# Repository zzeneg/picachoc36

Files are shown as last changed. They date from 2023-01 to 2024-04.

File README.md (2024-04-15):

# PicaChoc36

Low-profile split keyboard with 36 keys using XIAO controllers.

_Pica pica - european (common) magpie_

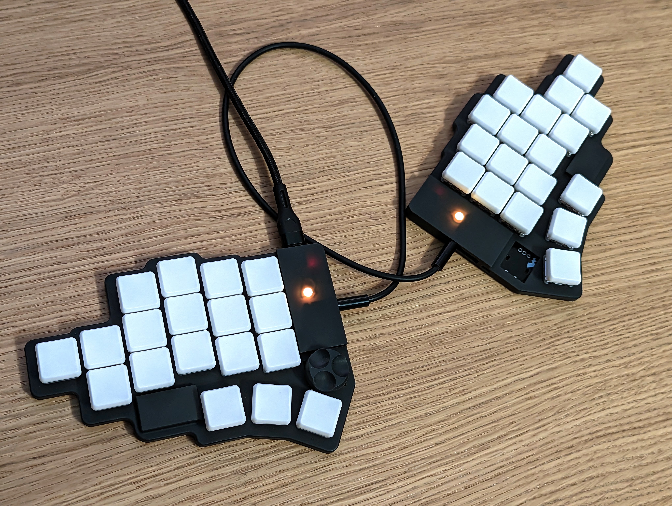
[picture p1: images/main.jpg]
main


## Features

- reversible PCB
- 36 soldered ChocV1 keys
- wired/wireless versions
- top pinky key moved to side
- 3D printed case

### Wired version

- XIAO RP 2040 controller
- QMK firmware
- TRRS or USB-C connection between halves
- rotary encoder on one side
- one status LED

### Wireless version

- XIAO BLE controller
- _[TODO]_ ZMK firmware
- rotary encoder on both sides (ZMK supports only main side for now)
- on/off toggle
- battery connectors

## Photos

wired version with 3d printed case

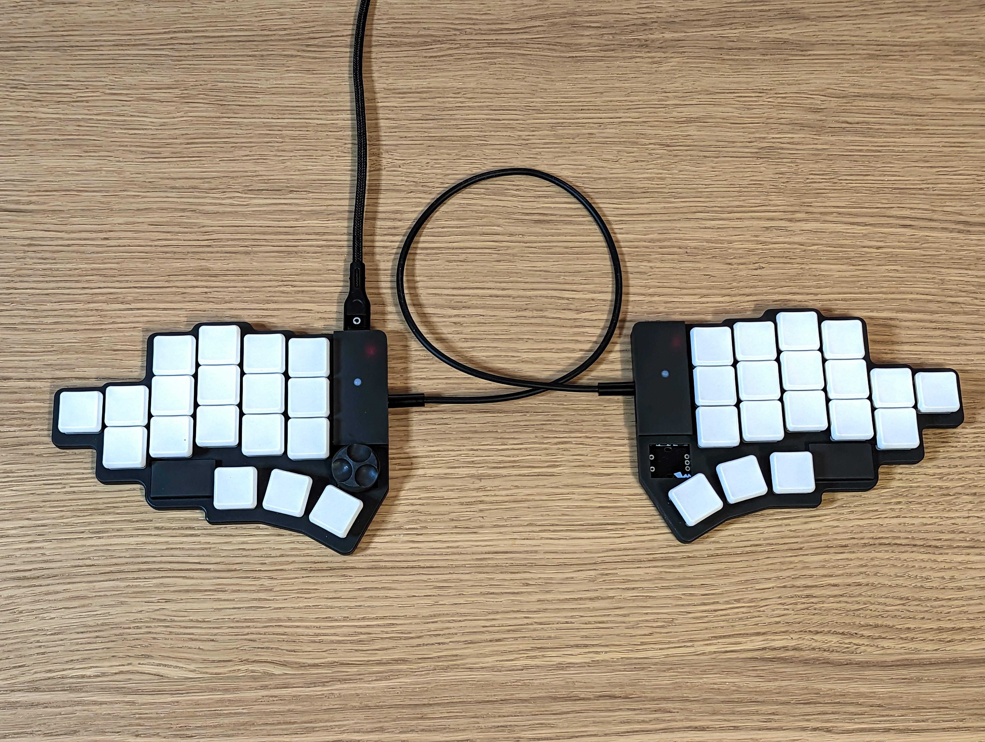
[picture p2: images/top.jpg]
top

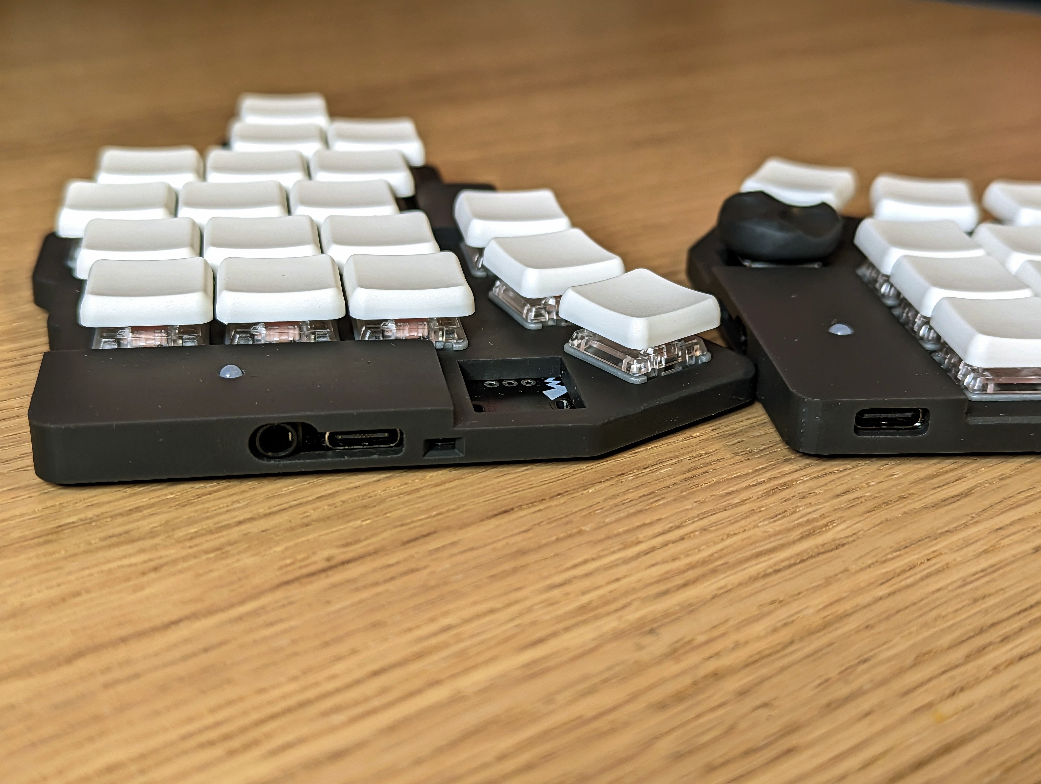
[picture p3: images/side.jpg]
side

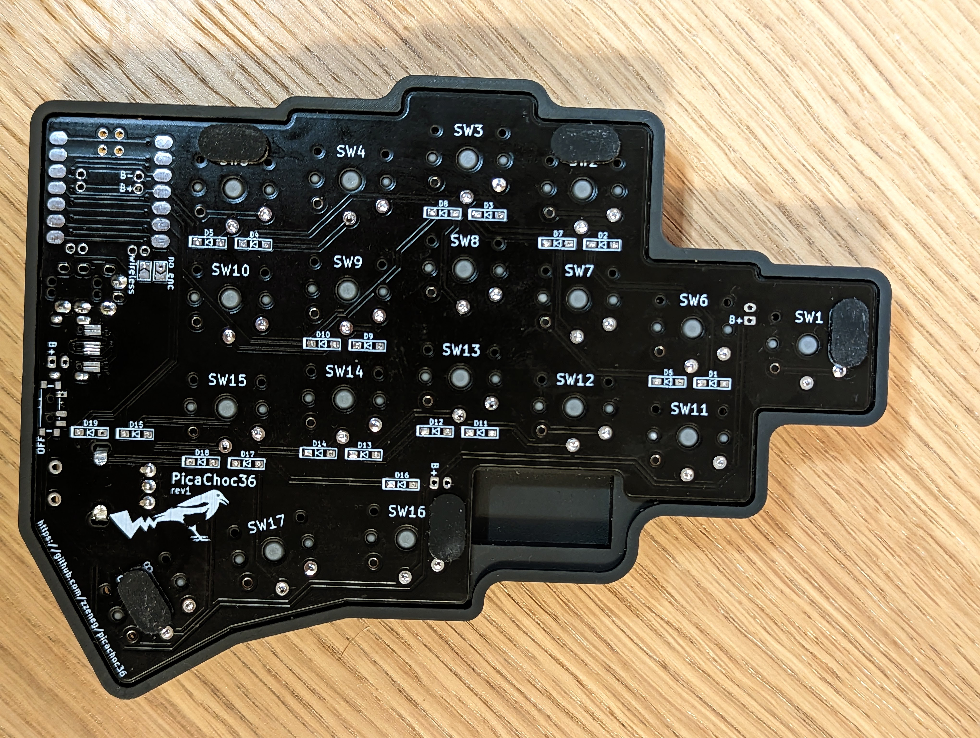
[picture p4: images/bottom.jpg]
bottom


build process

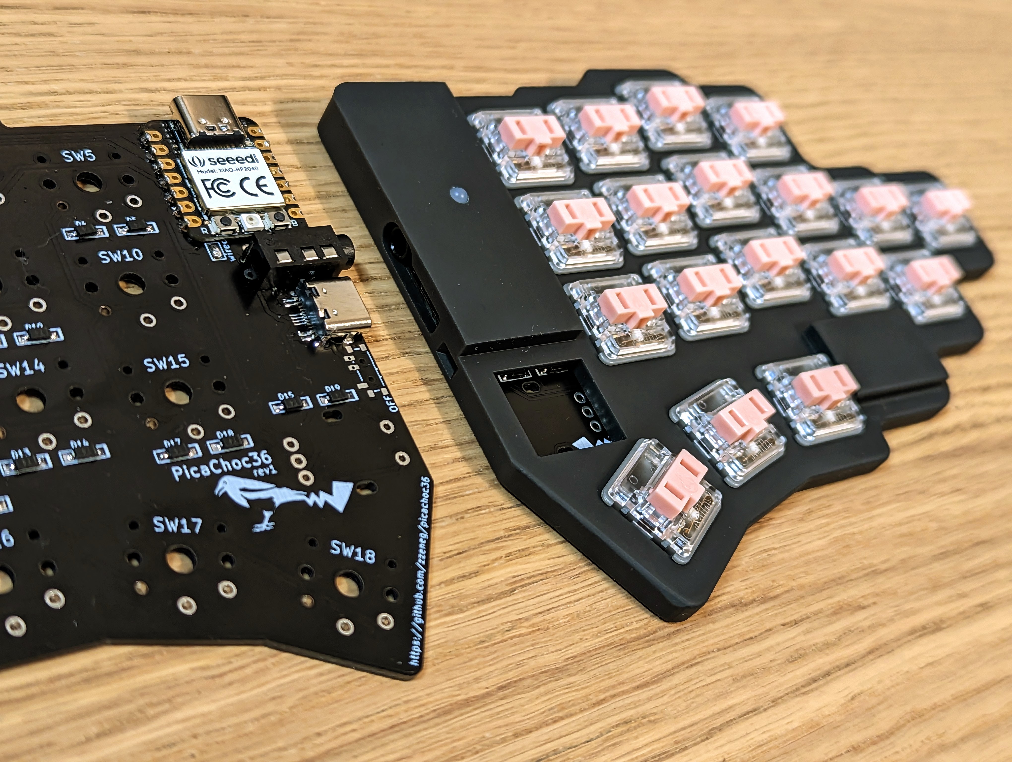
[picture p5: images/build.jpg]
build


battery compartment

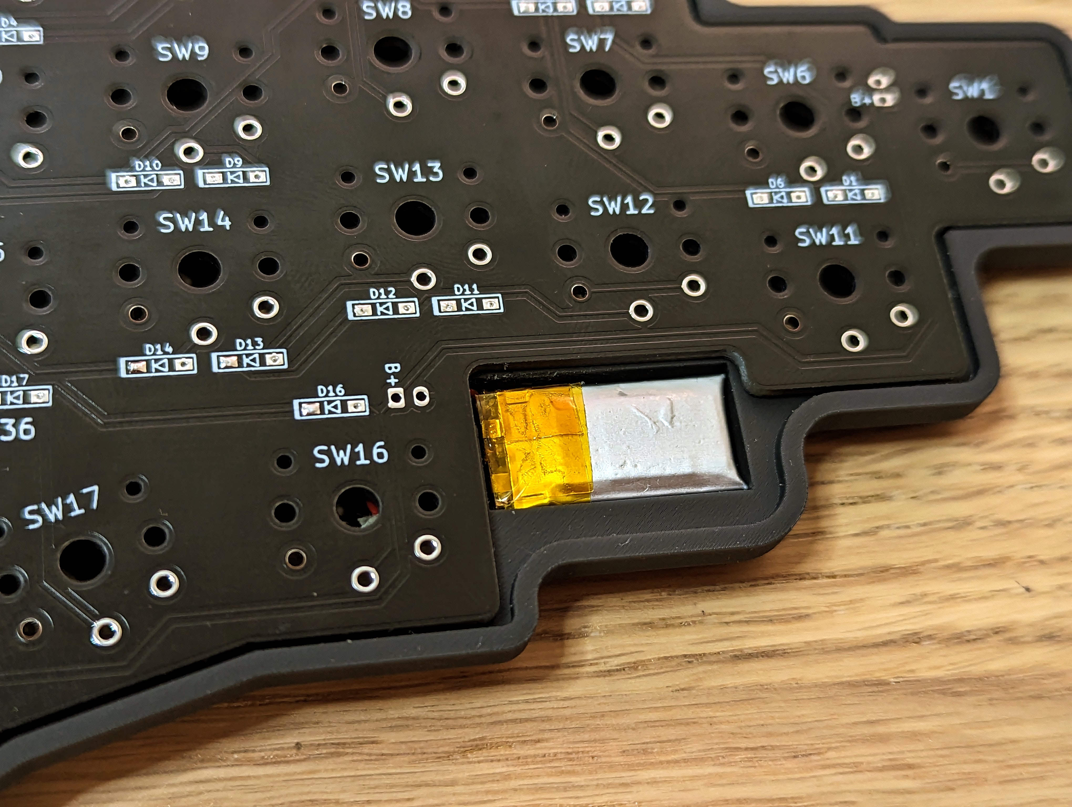
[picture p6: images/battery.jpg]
battery


## Firmware

- QMK - [my fork](https://github.com/zzeneg/qmk_firmware/tree/feature/zzeneg/keyboards/picachoc36), [compiled file](https://github.com/zzeneg/qmk_firmware/releases/download/zzeneg/picachoc36_default.uf2)
- Vial - [my fork](https://github.com/zzeneg/vial-qmk/tree/feature/zzeneg/keyboards/picachoc36), [compiled file](https://github.com/zzeneg/vial-qmk/releases/download/zzeneg/picachoc36_vial.uf2)
- _[TODO]_ ZMK

## Gerber files

- [PCB](./pcb/production/pcb.zip)

## Case files (STL - 3d printed)

Updated wired cases render:
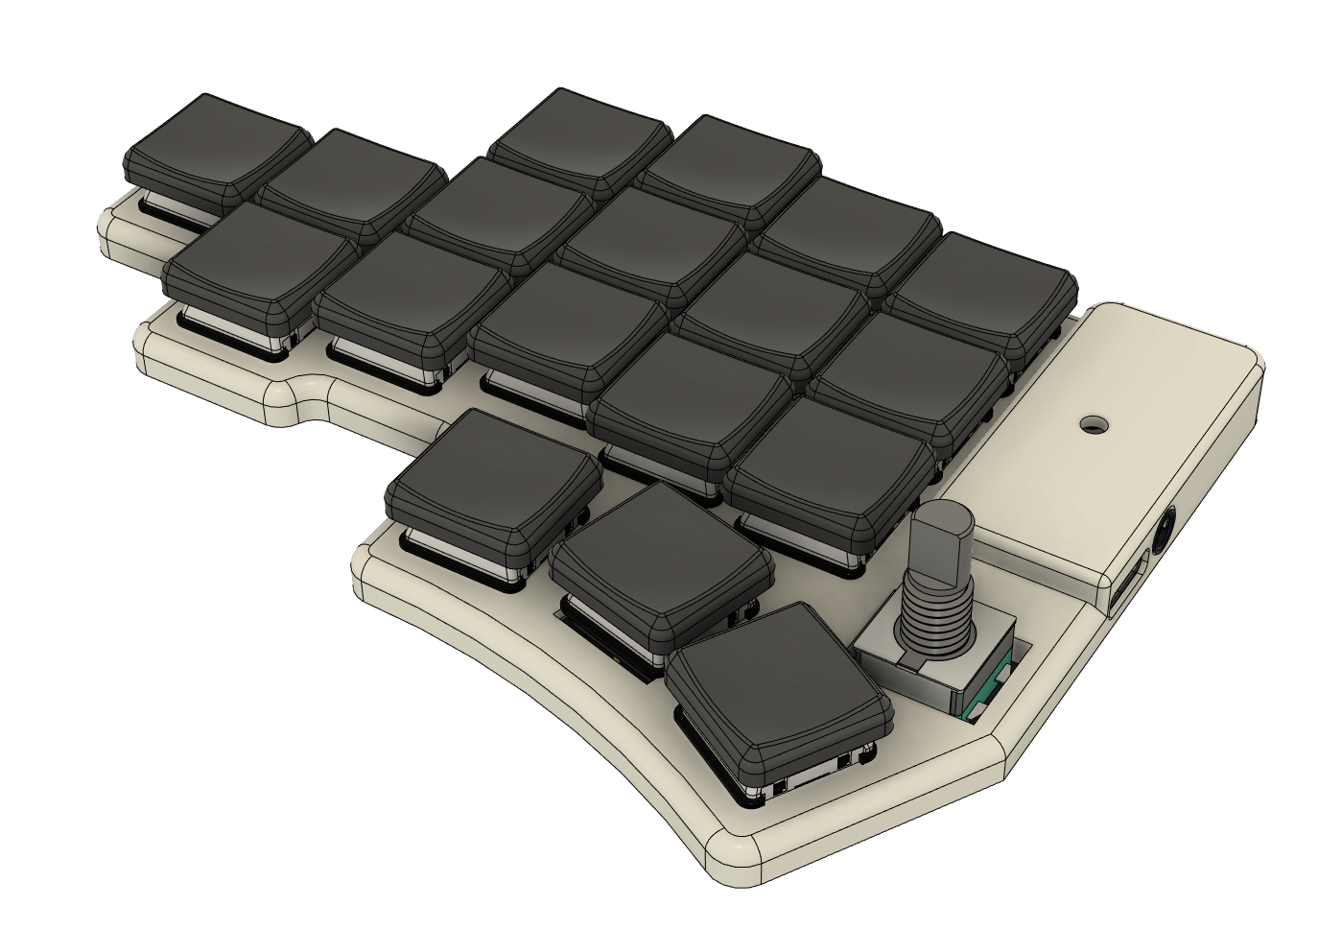
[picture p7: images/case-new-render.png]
Wired


- Wired - [Left](./stl/Plate_case%20v2_left-wired.stl), [left without encoder hole](./stl/Plate_case%20v2_left-wired-no-enc.stl), [right](./stl/Plate_case%20v2_right-wired.stl), [right without encoder hole](./stl/Plate_case%20v2_right-wired-no-enc.stl)
- Wireless - with battery compartment and encoder holes - [left](./stl/Plate-wireless-left.stl), [right](./stl/Plate-wireless-right.stl)
- _[Experimental]_ [Knob](./stl/Knob.stl) for low profile rotary encoder

## Bill of materials

- PCBs
- 3D printed case
- 2 XIAO MCUs - [RP2040](https://www.seeedstudio.com/XIAO-RP2040-v1-0-p-5026.html) for wired version, [nRF52840](https://www.seeedstudio.com/Seeed-XIAO-BLE-nRF52840-p-5201.html) for wireless
- 36 Choc V1 switches
- 36 SMD SOD-123 1N4148 diodes
- 1 or 2 EC11/12 rotary encoder with knob, [low profile](https://keycapsss.com/keyboard-parts/parts/220/alps-alpine-encoder-low-profile-ec12e1220301) is recommended
- _[Wired only]_ [2x USB-C 16pin connector](https://www.aliexpress.com/item/1005003670899595.html) and TRRS jack
- _[Wired only]_ USB-C or TRRS cable
- _[Wireless only]_ 2x Li-Ion 3.7V battery (battery compartment suited for 5×12×21 size)
- _[Wireless only]_ [2x on/off toggle MSK-12C02](https://www.aliexpress.com/item/4000685483225.html)

## Build log

**TODO**

Similar to all other keyboards. Main points:

- solder diodes on **top** side
- solder jumpers - choose wired or wireless on both sides
- for wired version only - solder "no enc" jumper on the side that **does not** have encoder
- for wireless version only - solder on/off switch on **top** side
- if you want USB-C connection, I recommend to solder both TRRS and USB-C to have a backup option, better safe than sorry. Check USB-C pins with multimeter for shorts/continuity, test that encoder works (it uses connection between splits)

⚠️ It's not possible to disassemble the keyboard after soldering switches, so **before** that:

- flash your MCUs with a firmware that supports bootmagic/QK_BOOT/&reset functions
- triple check all keys with tweezers

## Development

For proper KiCad setup install my [zzkeeb](https://github.com/zzeneg/zzkeeb/blob/main/README.md#installation) library.

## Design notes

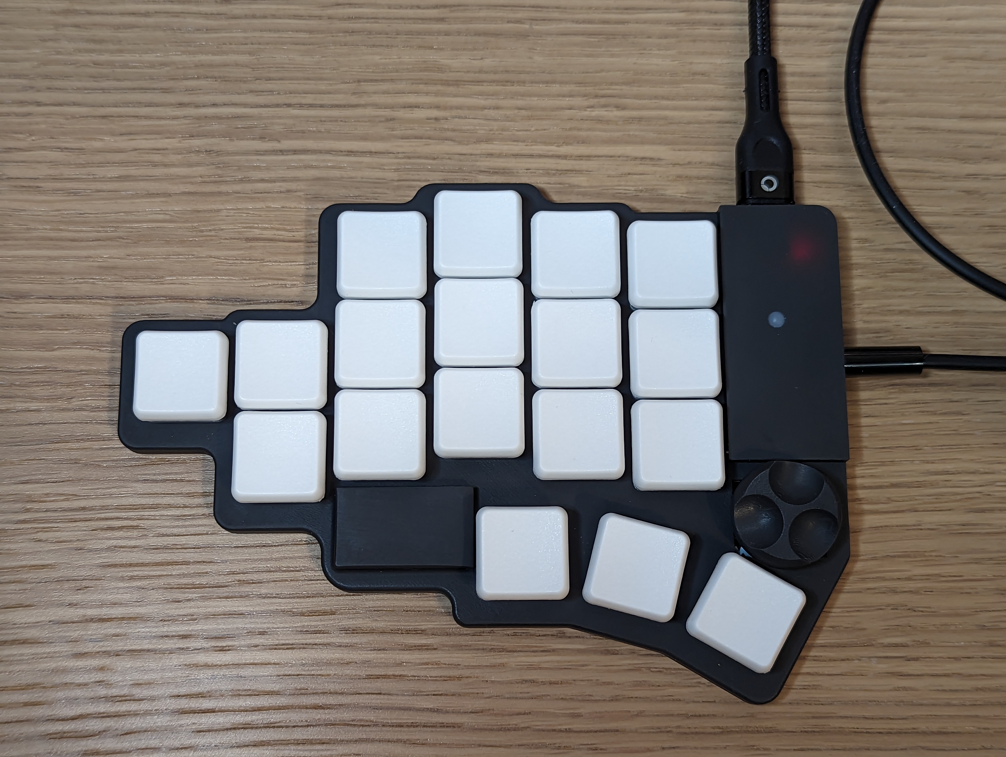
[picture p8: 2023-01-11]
images/half.jpg

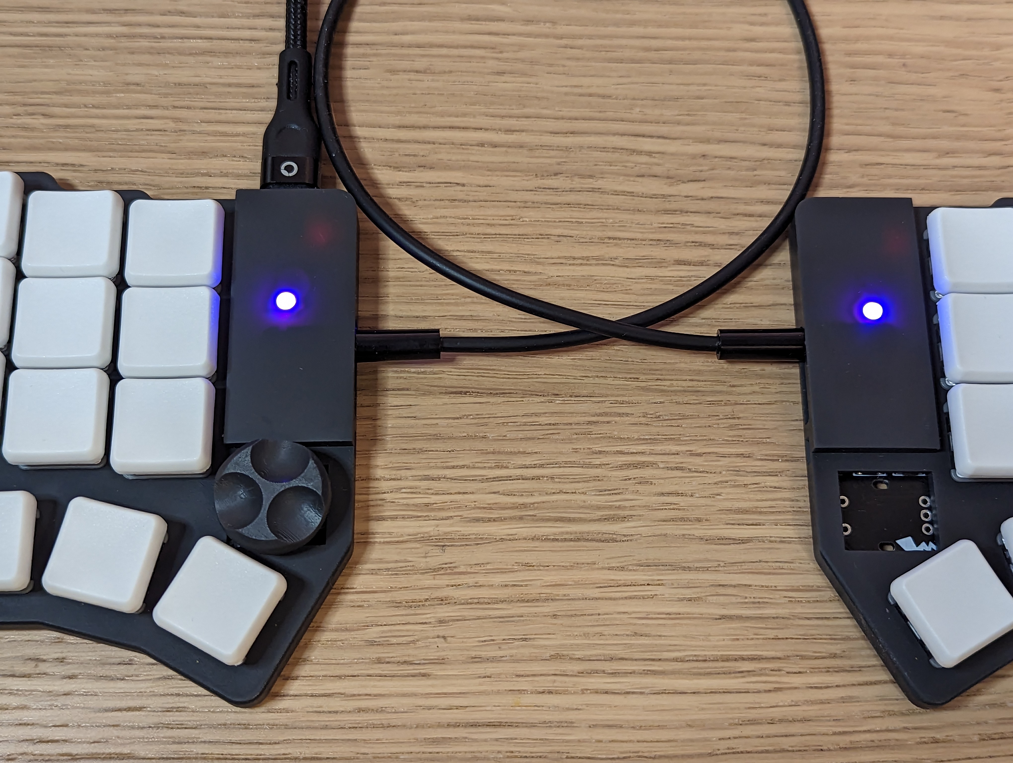
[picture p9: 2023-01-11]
images/led.jpg

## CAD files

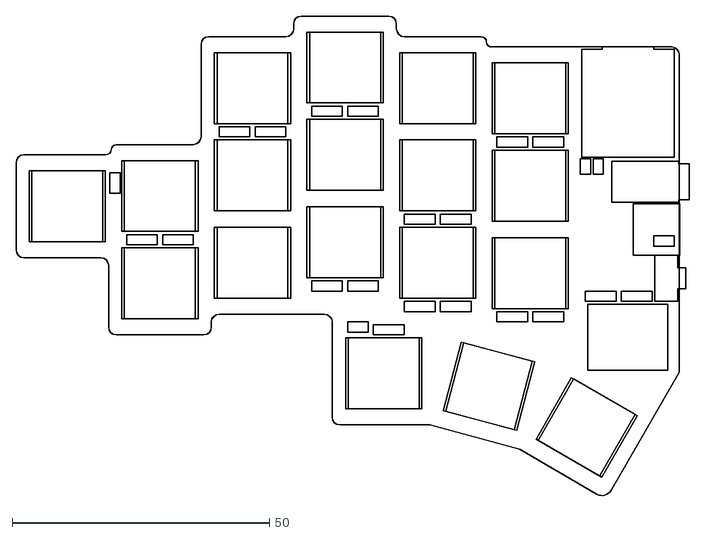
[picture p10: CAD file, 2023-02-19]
case/plate-Edge_Cuts.dxf
130.9 x 93.3

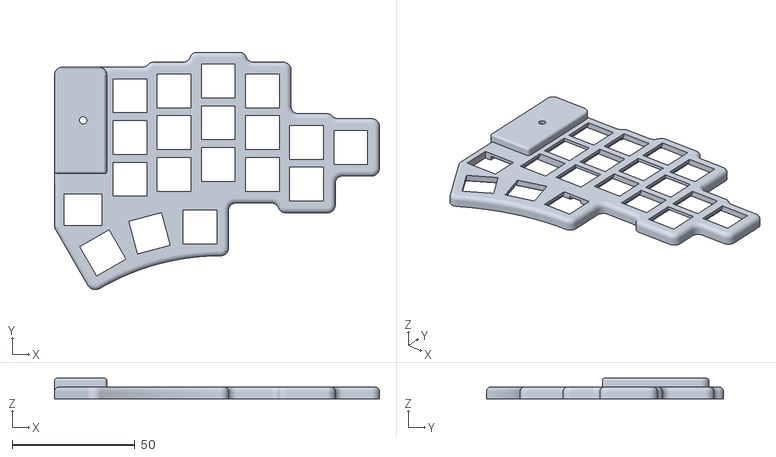
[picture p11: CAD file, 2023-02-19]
stl/Plate_case v2_right-wired.stl
132.4 x 96.7 x 8.40

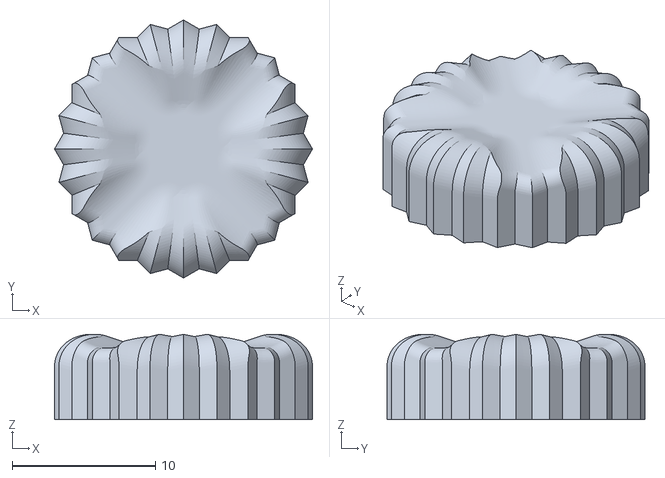
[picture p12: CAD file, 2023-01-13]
stl/Knob.stl
18.0 x 18.0 x 5.95

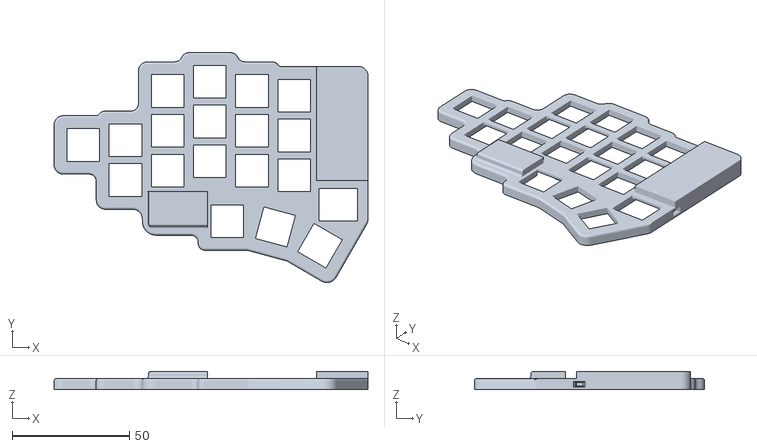
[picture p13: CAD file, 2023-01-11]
stl/Plate-wireless-left.stl
134.0 x 98.3 x 7.75

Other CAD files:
stl/Plate_case v2_left-wired.stl
stl/Plate_case v2_left-wired-no-enc.stl
stl/Plate_case v2_right-wired-no-enc.stl
stl/Plate-wireless-right.stl
case/Knob.f3d
case/pcb-right.f3d
case/pcb.f3d

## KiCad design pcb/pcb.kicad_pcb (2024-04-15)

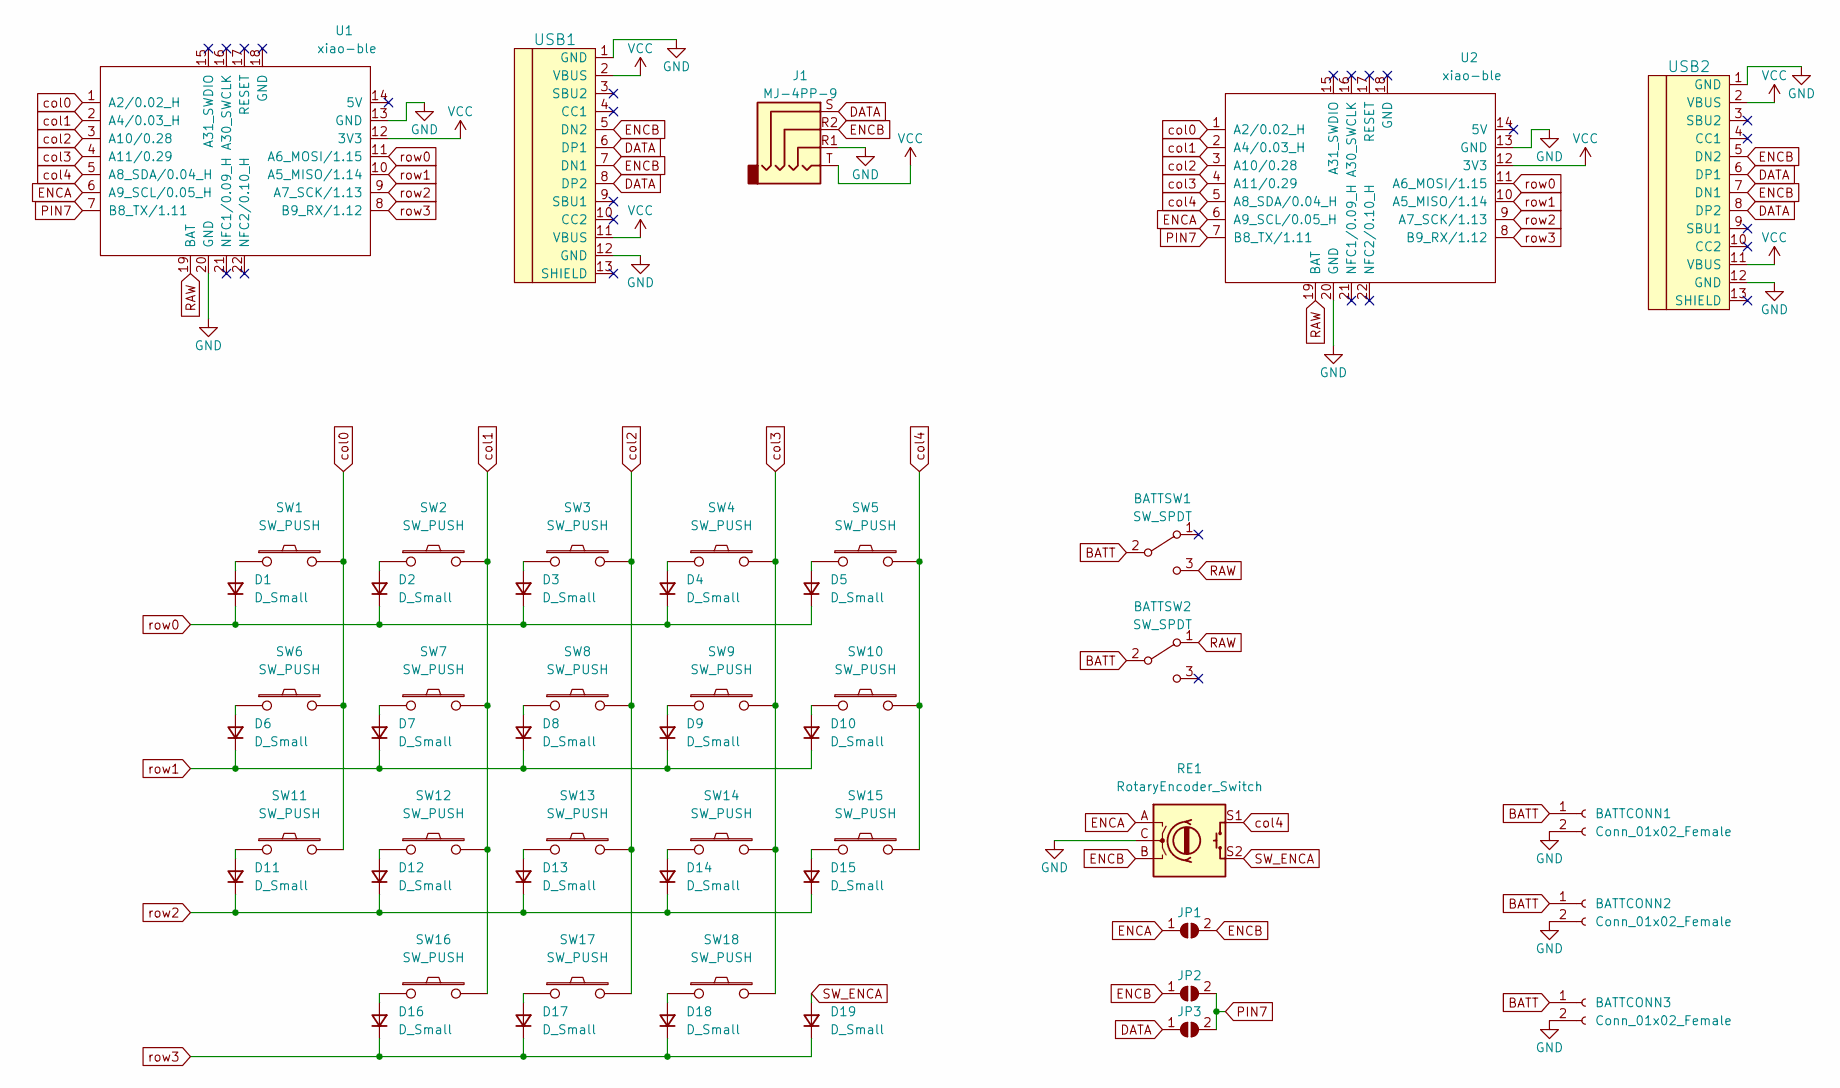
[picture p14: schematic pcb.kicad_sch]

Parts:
BATTCONN1, BATTCONN2, BATTCONN3: Conn_01x02_Female; Connector_JST-1x02-2.00mm
BATTSW1, BATTSW2: SW_SPDT; Switch_SPDT-PCM12
D1, D2, D3, D4, D5, D6, D7, D8, D9, D10, D11, D12, D13, D14, D15, D16, D17, D18, D19: D_Small; Diode_1N4148-SOD123-reversible
J1: MJ-4PP-9; Connector_TRRS-reversible
JP1, JP2, JP3: SolderJumper_2_Open; SolderJumper-2_P1.3mm_Open_TrianglePad1.0x1.5mm
RE1: RotaryEncoder_Switch; RotaryEncoder_EC11-reversible
SW1, SW2, SW3, SW4, SW5, SW6, SW7, SW8, SW9, SW10, SW11, SW12, SW13, SW14, SW15, SW16, SW17, SW18: SW_PUSH; Switch_ChocV1-reversible
U1, U2: xiao-ble; MCU_xiao-ble-smd
USB1, USB2: HRO-TYPE-C-31-M-12; Connector_HRO-TYPE-C-31-M-12-data

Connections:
BATT: BATTCONN1.1, BATTCONN2.1, BATTCONN3.1, BATTSW1.2 (B), BATTSW2.2 (B)
DATA: J1.S, JP3.1 (A), USB1.6 (DP1), USB1.8 (DP2), USB2.6 (DP1), USB2.8 (DP2)
ENCA: JP1.1 (A), RE1.A, U1.6 (A9_SCL/0.05_H), U2.6 (A9_SCL/0.05_H)
ENCB: J1.R2, JP1.2 (B), JP2.1 (A), RE1.B, USB1.5 (DN2), USB1.7 (DN1), USB2.5 (DN2), USB2.7 (DN1)
GND: BATTCONN1.2, BATTCONN2.2, BATTCONN3.2, J1.R1, RE1.C, U1.13 (GND), U1.20 (GND), U2.13 (GND), U2.20 (GND), USB1.1 (GND), USB1.12 (GND), USB2.1 (GND), USB2.12 (GND)
unnamed: D1.2 (A), SW1.1
unnamed: D2.2 (A), SW2.1
unnamed: D3.2 (A), SW3.1
unnamed: D4.2 (A), SW4.1
unnamed: D5.2 (A), SW5.1
unnamed: D6.2 (A), SW6.1
unnamed: D7.2 (A), SW7.1
unnamed: D8.2 (A), SW8.1
unnamed: D9.2 (A), SW9.1
unnamed: D10.2 (A), SW10.1
unnamed: D11.2 (A), SW11.1
unnamed: D12.2 (A), SW12.1
unnamed: D13.2 (A), SW13.1
unnamed: D14.2 (A), SW14.1
unnamed: D15.2 (A), SW15.1
unnamed: D16.2 (A), SW16.1
unnamed: D17.2 (A), SW17.1
unnamed: D18.2 (A), SW18.1
PIN7: JP2.2 (B), JP3.2 (B), U1.7 (B8_TX/1.11), U2.7 (B8_TX/1.11)
RAW: BATTSW1.3 (C), BATTSW2.1 (A), U1.19 (BAT), U2.19 (BAT)
SW_ENCA: D19.2 (A), RE1.S2
VCC: J1.T, U1.12 (3V3), U2.12 (3V3), USB1.2 (VBUS), USB1.11 (VBUS), USB2.2 (VBUS), USB2.11 (VBUS)
col0: SW1.2, SW6.2, SW11.2, U1.1 (A2/0.02_H), U2.1 (A2/0.02_H)
col1: SW2.2, SW7.2, SW12.2, SW16.2, U1.2 (A4/0.03_H), U2.2 (A4/0.03_H)
col2: SW3.2, SW8.2, SW13.2, SW17.2, U1.3 (A10/0.28), U2.3 (A10/0.28)
col3: SW4.2, SW9.2, SW14.2, SW18.2, U1.4 (A11/0.29), U2.4 (A11/0.29)
col4: RE1.S1, SW5.2, SW10.2, SW15.2, U1.5 (A8_SDA/0.04_H), U2.5 (A8_SDA/0.04_H)
row0: D1.1 (K), D2.1 (K), D3.1 (K), D4.1 (K), D5.1 (K), U1.11 (A6_MOSI/1.15), U2.11 (A6_MOSI/1.15)
row1: D6.1 (K), D7.1 (K), D8.1 (K), D9.1 (K), D10.1 (K), U1.10 (A5_MISO/1.14), U2.10 (A5_MISO/1.14)
row2: D11.1 (K), D12.1 (K), D13.1 (K), D14.1 (K), D15.1 (K), U1.9 (A7_SCK/1.13), U2.9 (A7_SCK/1.13)
row3: D16.1 (K), D17.1 (K), D18.1 (K), D19.1 (K), U1.8 (B9_RX/1.12), U2.8 (B9_RX/1.12)

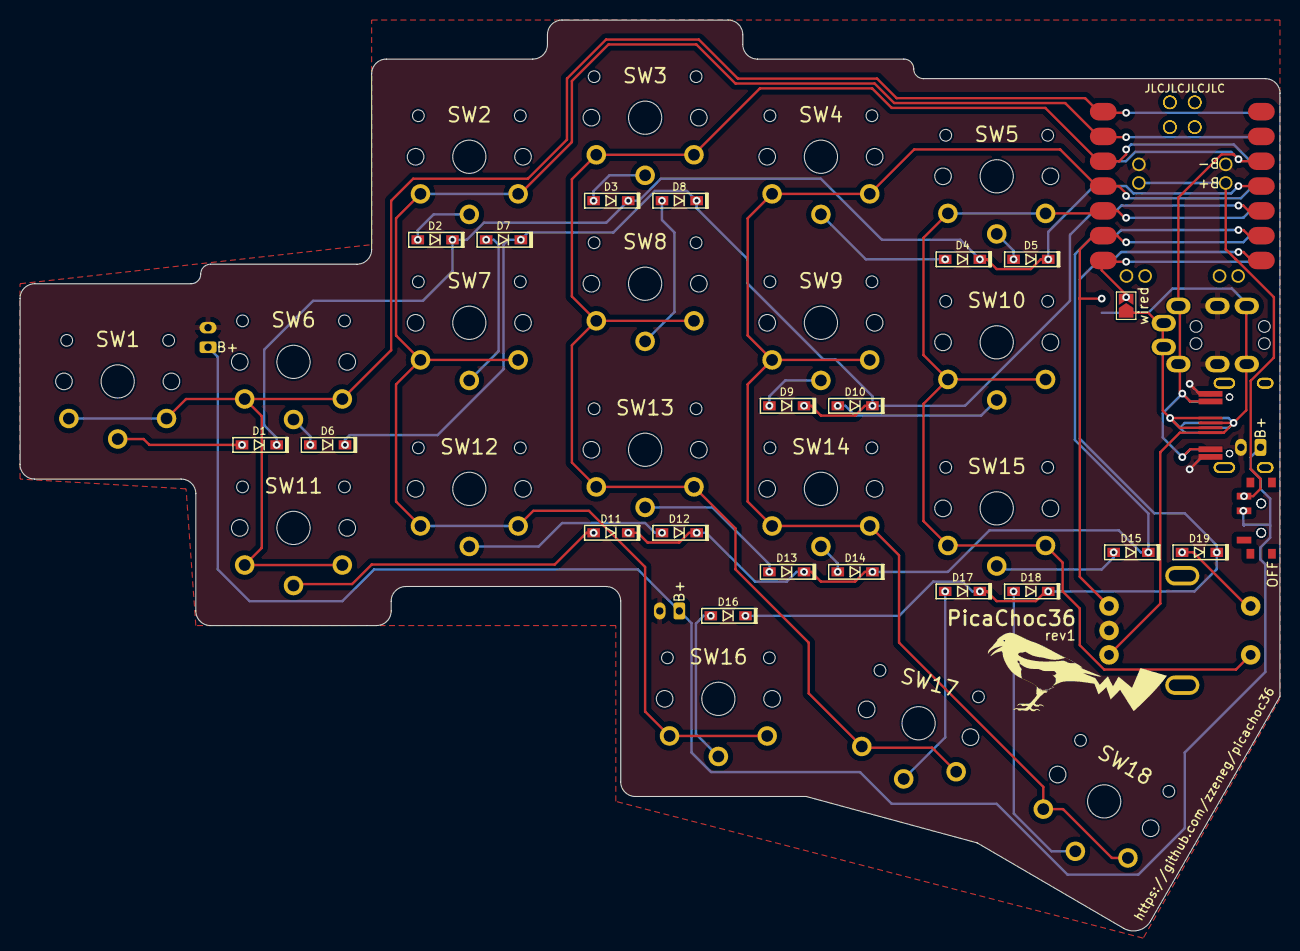
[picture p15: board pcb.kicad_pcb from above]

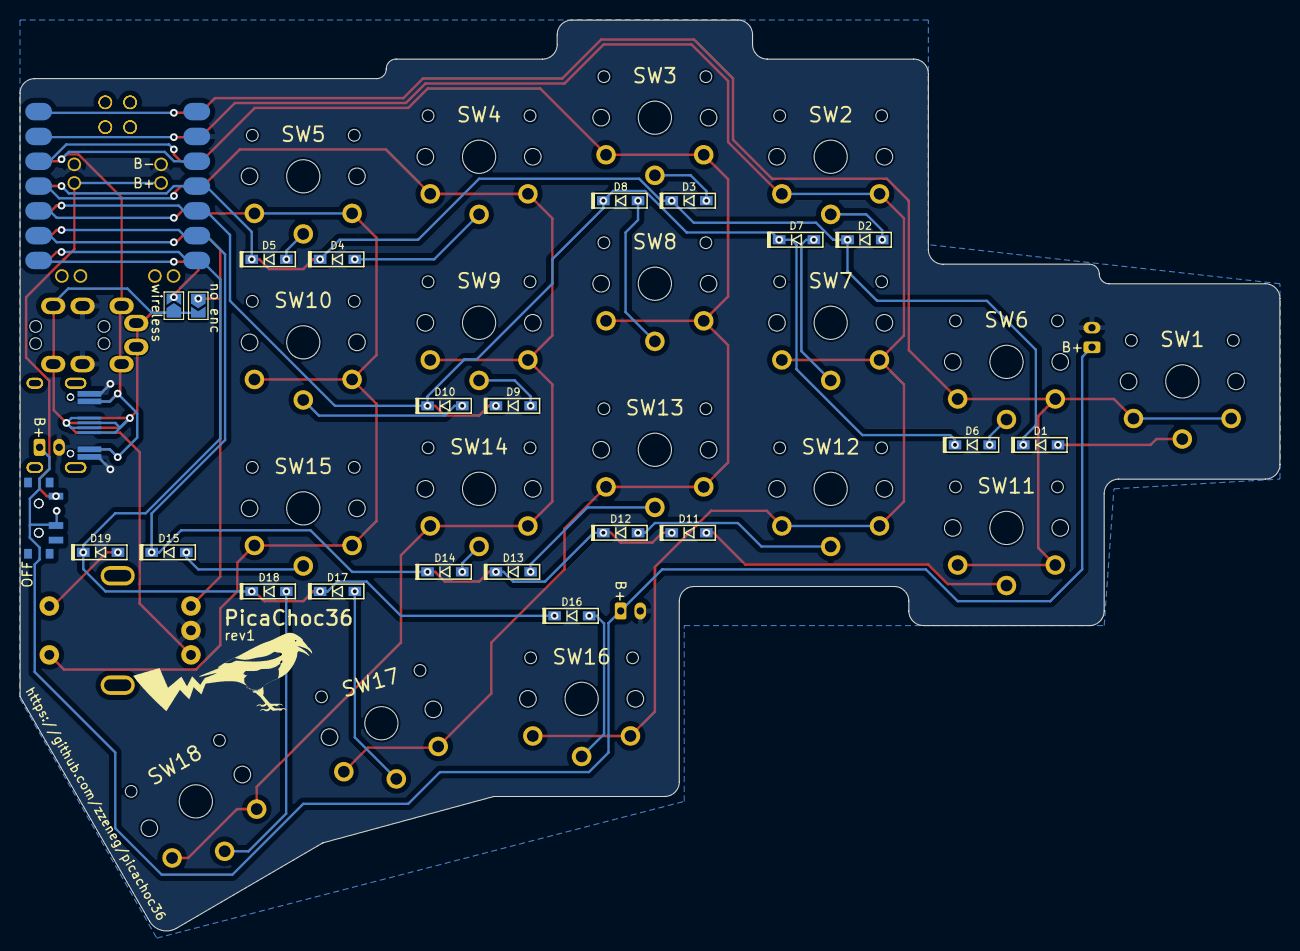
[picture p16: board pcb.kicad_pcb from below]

Board: 2 copper layers, 129.0 x 93.3 mm, 51 parts (5 on the bottom side), 36 nets.

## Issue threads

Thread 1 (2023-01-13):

Question: Top-mounted diodes and case clearance

breckenedge, 2023-01-13:
Thanks for releasing this project. I'm eager to get my hands on one.

Any clearance issues with the top-mount diodes and the case? I saw your BOM indicated `1N4148 SOD-123 SMD` diodes, which look to be about 1.4mm tall. Is that right? Do you have any pics without the case on?

I'm happy to order the parts and provide photos for a build guide if that helps.

zzeneg, 2023-01-14:
Thanks!

I think the only pic without case I have is this one - 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

No clearance issues, case has empty spaces where diodes are located
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

Here you can see diodes inside case
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

I hope it'll work for you and I'd be very greatful for a build guide of course!

zzeneg, 2023-01-14:
Also I added more details to build guide, hope it makes more sense now. And fixes mentioning choc v2 switches🤦

breckenedge, 2023-01-14:
Oh perfect! I ordered PCBs/Cases from JLC and SMDs/Rotaries/MCUs from Alibaba. I was gonna ask about those choc-v2s, but your photos made it pretty obvious that they're v1s, no?

zzeneg, 2023-01-14:
Yep, it's V1 only! Copy pasted BOM from previous keyboard and didn't notice...

Closed 2023-01-19.

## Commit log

2022-12-20 initial pcb
    [Rotary Encoder.step, pcb.kicad_pcb, pcb.kicad_sch]
2022-12-20 add case
    [Plate-left.stl, Plate-right.stl, Plate.f3d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]
2022-12-21 improve case
    [Plate-left.stl, Plate-right.stl, Plate.f3d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]
2022-12-22 improve pcb
    [pcb.kicad_pcb, pcb.kicad_sch]
2022-12-22 fix case
    [Plate-left.stl, Plate-right.stl, Plate.f3d]
2023-01-10 small fix for encoder footprint
    [pcb.kicad_pcb]
2023-01-11 move usb-c connector a bit
    [pcb.kicad_pcb]
2023-01-11 fix choc footprint
    [pcb.kicad_pcb]
2023-01-11 update cases
    [Plate-left.stl, Plate-right.stl, Plate-wired-left-noenc.stl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]
2023-01-12 Revert "fix choc footprint"
    This reverts commit fcca782c8e4dbdc4b8a54a5bbd694bc51ef22255.
    [pcb.kicad_pcb]
2023-01-13 add knob
    [Knob.f3d, Knob.stl]
2023-02-18 migrate to my own library
    [pcb.kicad_pcb, pcb.kicad_sch]
2023-02-19 update wired cases
    [Plate-wired-left-noenc.stl, Plate-wired-left.stl, Plate-wired-right-noenc.stl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]
